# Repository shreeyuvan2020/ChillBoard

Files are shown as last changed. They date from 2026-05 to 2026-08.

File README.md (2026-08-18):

 # The Chillboard
 ## The perfect ergonomic keyboard for chilling
 ## Features
 - Uses Xiao NRF52840 for low power usage and BLE capabilities
 - Wireless design with a 2000 mAh battery and BLE
 - CPG1350 hotswap sockets for customizabilty
 - Low profile choc switches for portability
 - Neopixel backlighting for layer switching
 - OLED panel for battery percentage
 - Tray mounted for easy assembly
 - Rotary encoder for volume control
 - PIR sensor for energy conservation
 - Ortholinear layout with a thumb cluster to reduce strain
## Reasons I built this
 - Right now, I type on a laptop keyboard and am scared that I might get carpal tunnel.
 - The switches on my other keyboard are very loud, and are not the best for me. Hotswap sockets let me customize the feel.
 - The keyboard doesn't have backlighting.
## Schematic
 For the schematic, I used hierarchial sheets to organize everything. There are 2 hierarchial sheets for each side of the pcb, and a hierarchial sheet in each one of those for the large neopixel matrix. 

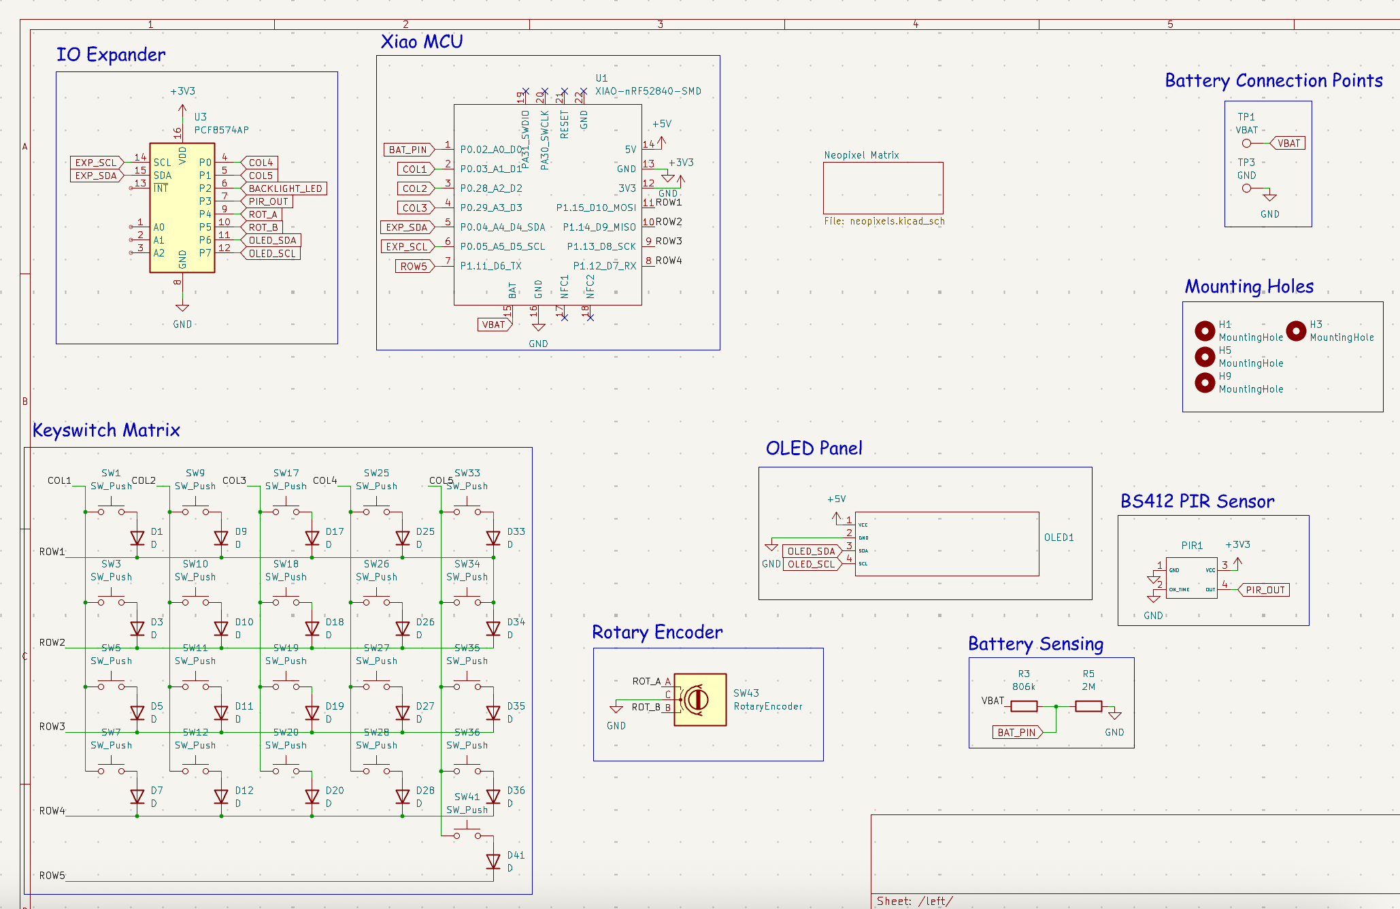
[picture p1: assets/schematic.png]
Schematic
 - 
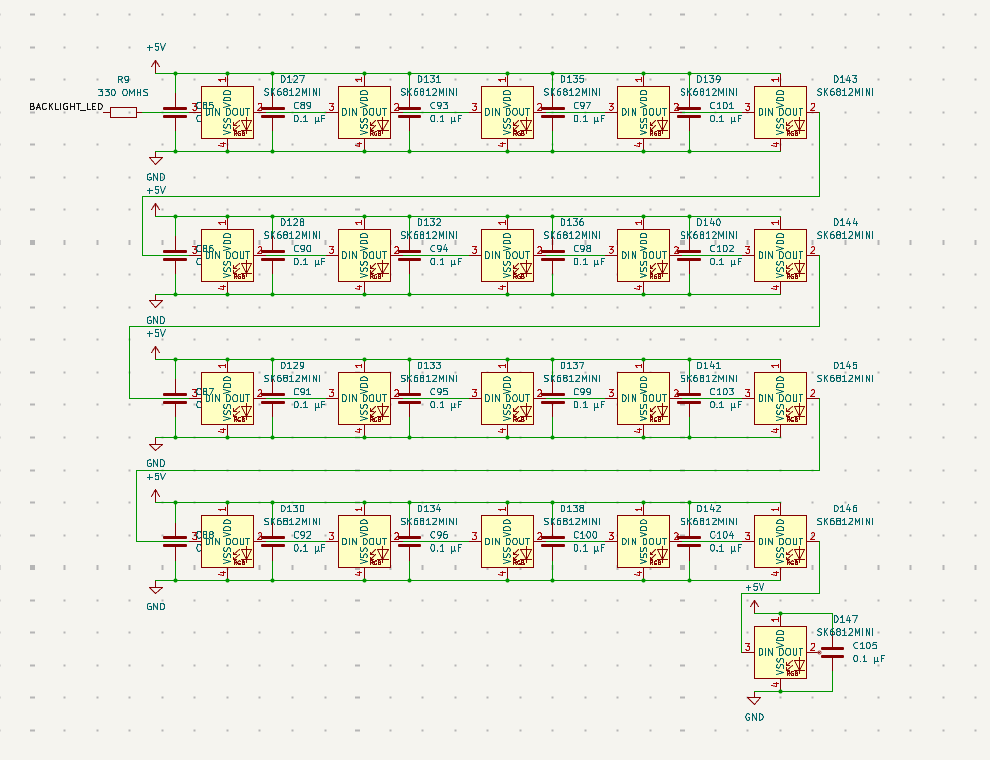
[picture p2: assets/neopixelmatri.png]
Neopixels
 - 
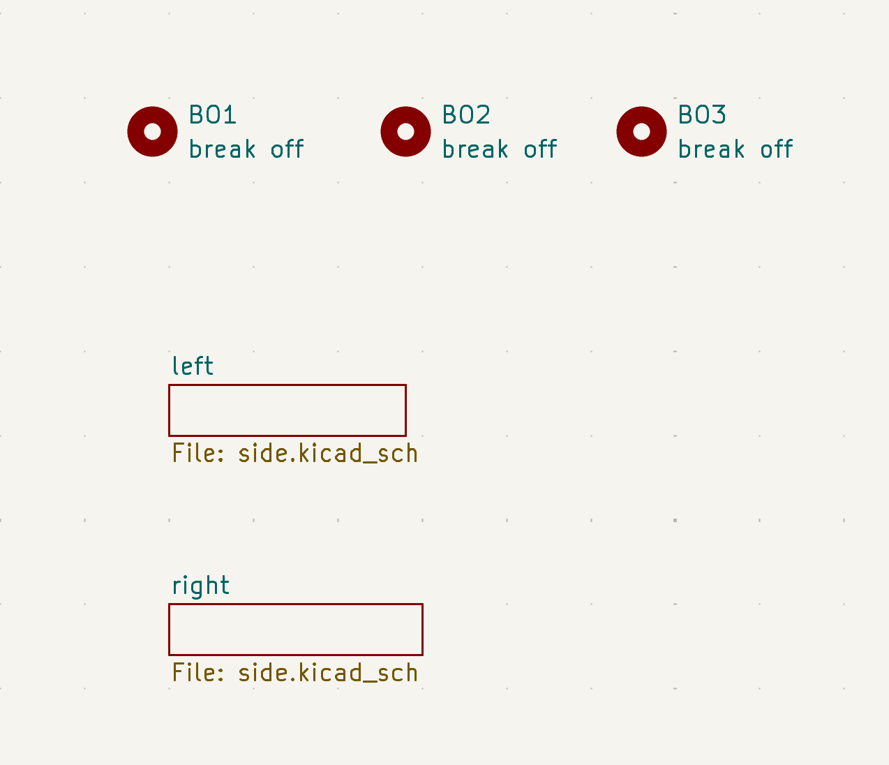
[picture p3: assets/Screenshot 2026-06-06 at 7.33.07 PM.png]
FullFull
 - 
## PCB
 I designed the PCB with mousebites to make the split keyboard easy to manufacture. I thought of making a reversible PCB at first, but it would be very difficult with an OLED. 
  ### Left side of the PCB 
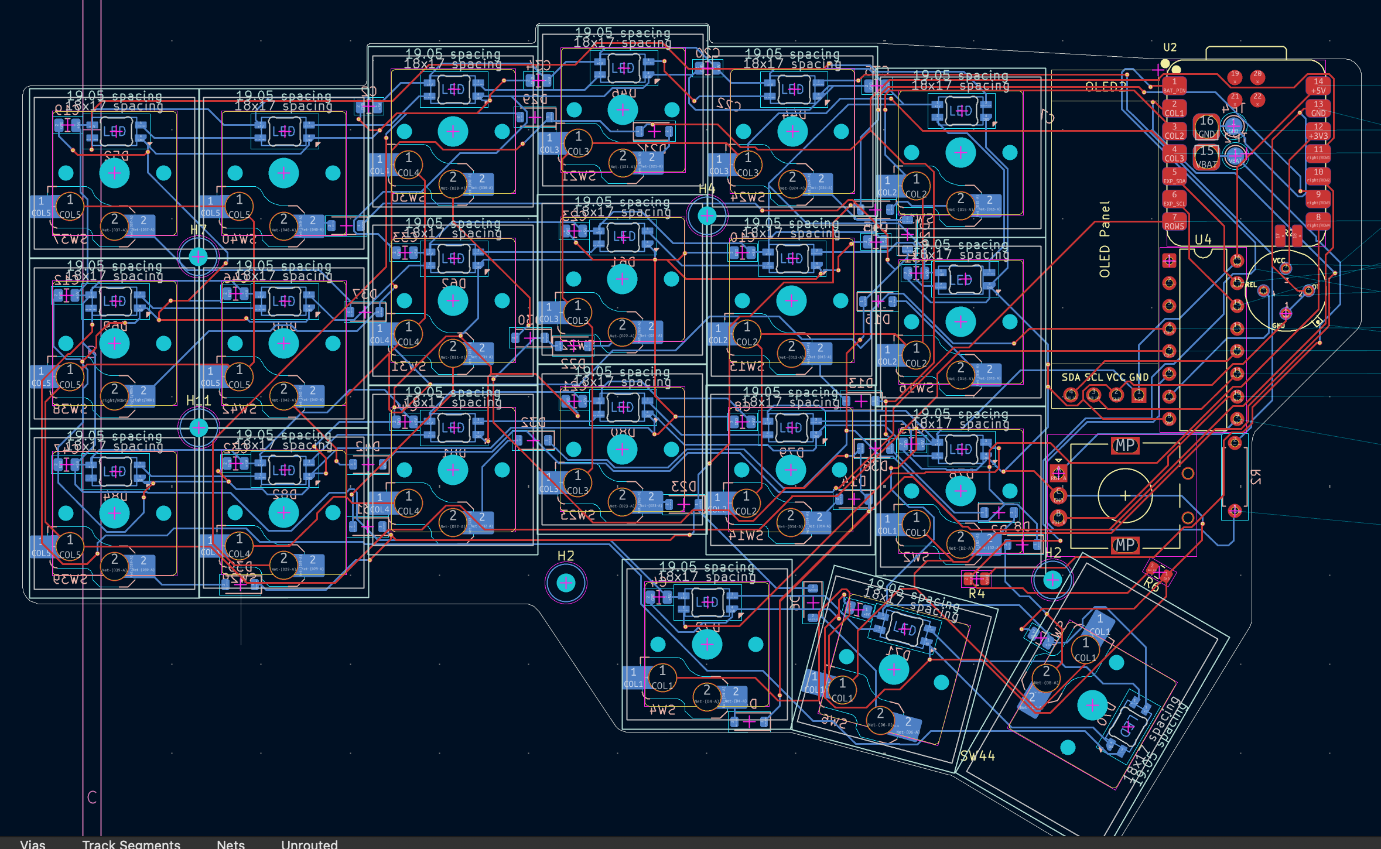
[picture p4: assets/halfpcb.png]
Left
  
  ### Full PCB
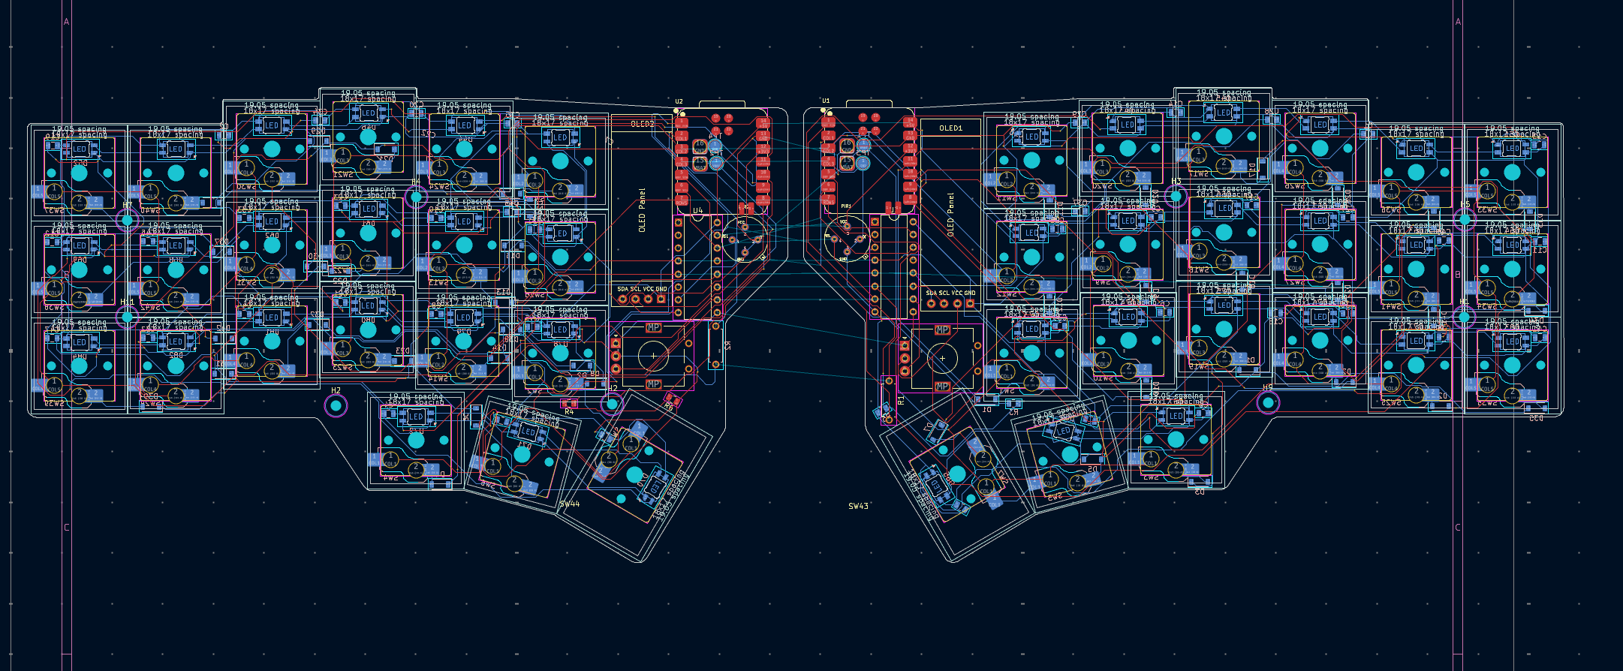
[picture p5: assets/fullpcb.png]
Full
  
  ### 3D View
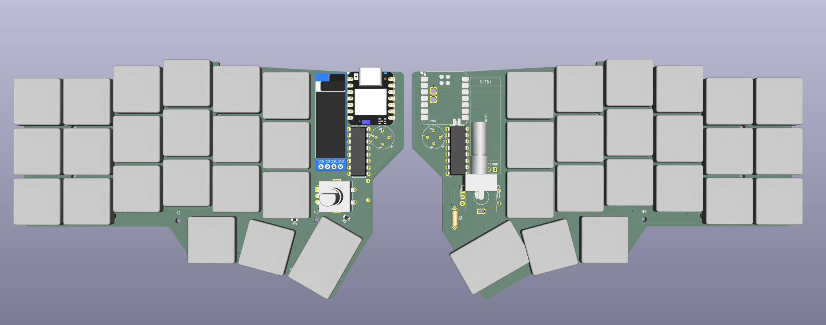
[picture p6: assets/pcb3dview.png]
3D
  
## CAD
 I designed the CAD with ease of assembly in mind. That is why I designed it with no tolerances, so that it could completely friction fit(I added screw holes for the worst case). I decided to print it with an extra fine setting on my Bambu Lab A1 Mini 3D printer, and it turned out great. 
 ### Bottom Case
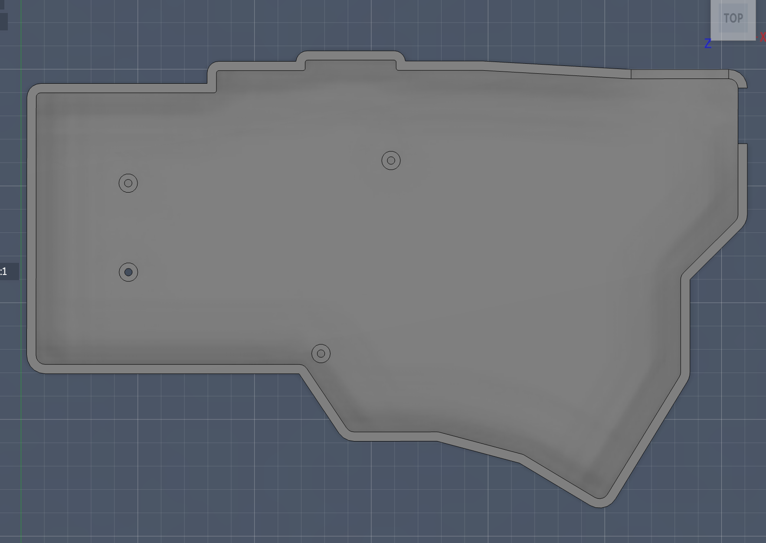
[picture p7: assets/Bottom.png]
Bottom
 
 ### Top Plate
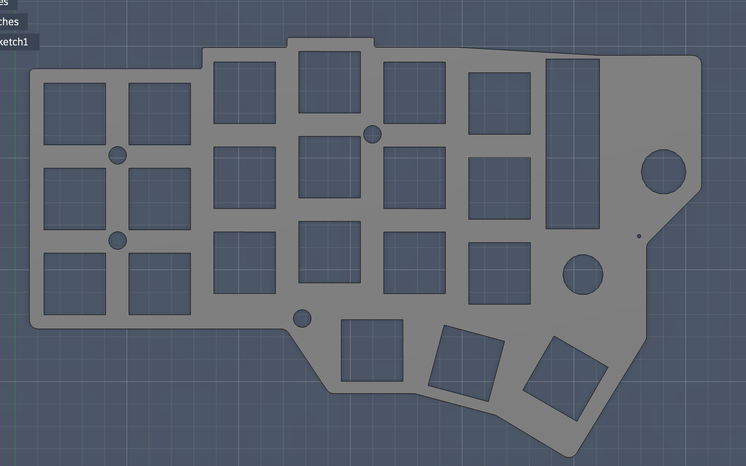
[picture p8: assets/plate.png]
Plate
 
 ### Full Assembly
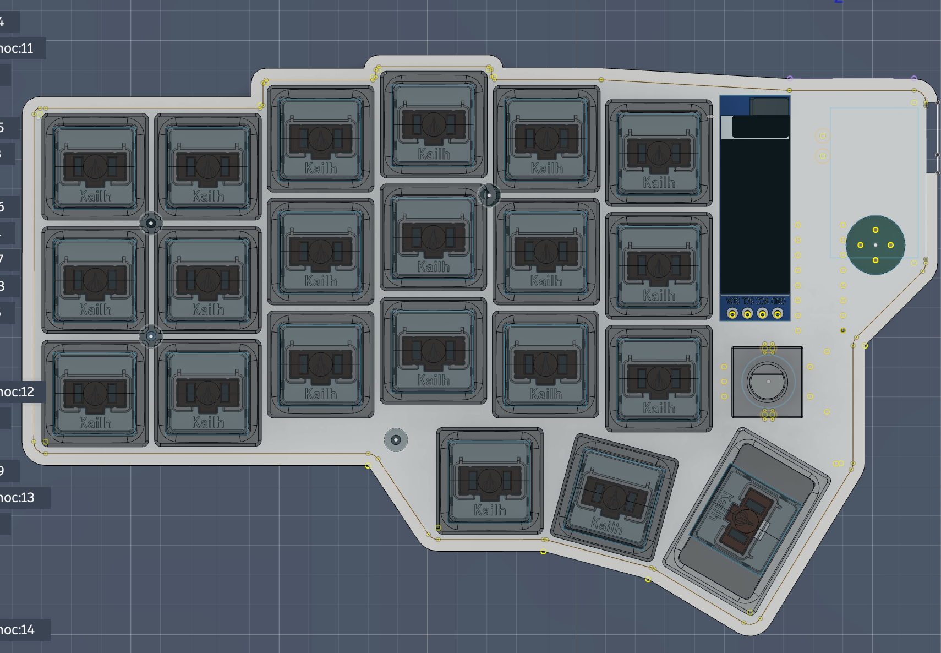
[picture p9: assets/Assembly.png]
Assembly
 
 ### Pictures of it Assembled
 Assembly
 Assembly
## My Zine
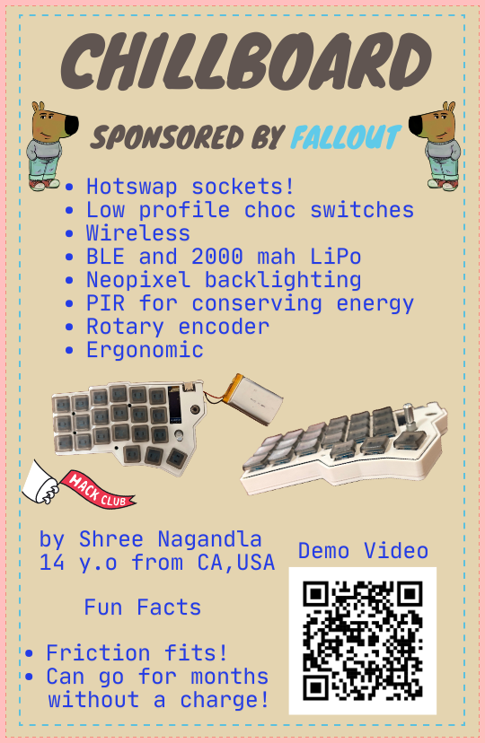
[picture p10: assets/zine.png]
zine

Zine is at zine.pdf too
## Assembly Instructions
 - First, obviously fabricate the PCB and solder everything.
 - Next is printing the plate and case.
 - Print with very fine settings as it friction fits, I printed with 0.08 mm High Quality @BBL on my Bambu Labs A1 Mini.
 - Be careful when removing the plate and bottom from the print bed as it could break
 - Obviously print two of each, two plates and two bottom cases
 - Then, go into the Firmware folder, open the submodule, and open Github Actions
 - Click the latest build and download the firmware artifact.
 - Then, plug in a USB cable into the Xiao and hit the reset button 2 times
 - A drive should show up, drop the first file that says settings-reset etc.
 - The drive should disappear, wait about 5 seconds and then do the same thing again
 - Then drop the file that starts with custom21
 - Now disconnect the cable, and it should show up as a BLE device
 - Connect to it then put the PCB into the bottom case
 - Then put the plate on top of it and place the keycaps on top of that to secure it.
 - You're good to go!
## Credits
 This project is inspired by the Corneucopia project by @DynamicWhiteHat.
 It used Autodesk Fusion for CAD, Kicad 10 for the PCB, and is sponsored by Hack Club Fallout! Thanks to Hack Club for sponsoring this!

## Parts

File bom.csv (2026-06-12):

Description | Price | Link
70 Low Profile Kailh Switches | 21.32 | https://www.aliexpress.us/item/3256811624147176.html
1N4148 SOD 123 Diodes | 0.51 | https://www.lcsc.com/product-detail/C33962554.html
0.1 uF 0805 Capacitors | 1.07 | https://www.lcsc.com/product-detail/C14663.html
45 SK6812MINI-E LED | 3.92 | https://www.lcsc.com/product-detail/C5149201.html
50 CPG1350 Sockets | 11.9 | https://www.amazon.com/Mechkeeb-Kailh-Low-Hot-swappable-Socket/dp/B0BS3JYJJQ?th=1
2 EC11 Rotary Encoders | 4 | https://www.lcsc.com/product-detail/C470754.html?
0.91 Inch SSD1306 OLED | 4.45 | https://www.lcsc.com/product-detail/C5248081.html
BS412 PIR Sensors | 2.05 | https://www.lcsc.com/product-detail/C410378.html
PCF8574AP | 1.59 | https://www.lcsc.com/product-detail/C398072.html?
2M Ohm Resistor | 0.22 | https://www.lcsc.com/product-detail/C2907316.html?
2 XIAO nrf52840 | 24.78 | https://www.seeedstudio.com/Seeed-XIAO-BLE-nRF52840-p-5201.html
PCB Order + Stencil | 24.63
Customs | Will Cover Myself
Total | 100.44

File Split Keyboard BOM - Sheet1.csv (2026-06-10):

Description | Price | Link | Column 4 | Column 5 | Column 6
Low Profile Kailh Switches | 29.61 | https://www.amazon.com/Mechanical-Keyboard-switches-Chocolate-Blue-70Pcs
1N4148 SOD 123 Diodes | 0.51 | https://www.lcsc.com/product-detail/C33962554.html
0.1 uF 0805 Capacitors | 1.07 | https://www.lcsc.com/product-detail/C14663.html
45 SK6812MINI-E LED | 3.92 | https://www.lcsc.com/product-detail/C5149201.html
50 CPG151101S11 Sockets | 7.9 | https://www.amazon.com/Hot-swap-CPG151101S11-Mechanical-Keyboard-Accessories/dp/B0BVH6M5FP?th=1
2 EC11 Rotary Encoders | 4 | https://www.lcsc.com/product-detail/C470754.html?
0.91 Inch SSD1306 OLED | 4.45 | https://www.lcsc.com/product-detail/C5248081.html
BS412 PIR Sensor | 2.05 | https://www.lcsc.com/product-detail/C410378.html
PCF8574AP | 1.59 | https://www.lcsc.com/product-detail/C398072.html?
2M Ohm Resistor | 0.22 | https://www.lcsc.com/product-detail/C2907316.html?
2 XIAO nrf52840 | 24.78 | https://www.seeedstudio.com/Seeed-XIAO-BLE-nRF52840-p-5201.html
PCB Order + Stencil | 24.63
DHL Customs | 43.98
Total | 148.71

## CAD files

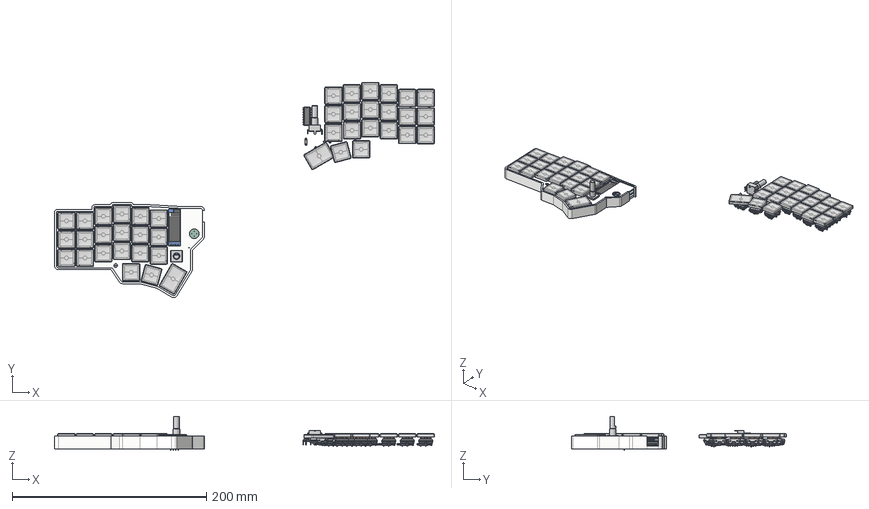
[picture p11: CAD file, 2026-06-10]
CAD/StepFiles/chillboardrender.step
391.2 x 221.6 x 35.4 mm
Chillboard_PCB
chillboardplate
OLED_0.91_128x32_1
Pin Header 4 x 1 TH 2.54mm Pitch
RESC-0603 x 13
2SD0601A
R_0805_2012Metric x 4
RotaryEncoder_Alps_EC11E_Vertical_H20mm x 2
DIP-16_W7.62mm x 2
chillboardtuffie6 1.7.1
R_Axial_DIN0207_L6.3mm_D2.5mm_P7.62mm_Horizontal x 2
LED_SK6812MINI-E x 42
C_0805_2012Metric x 42
D_SOD-123 x 42
pin x 84
socket x 42
SW_Kailh_Choc_V1 x 42
1x1 x 40
1x1.5 x 2
Chillboard_PCB_1

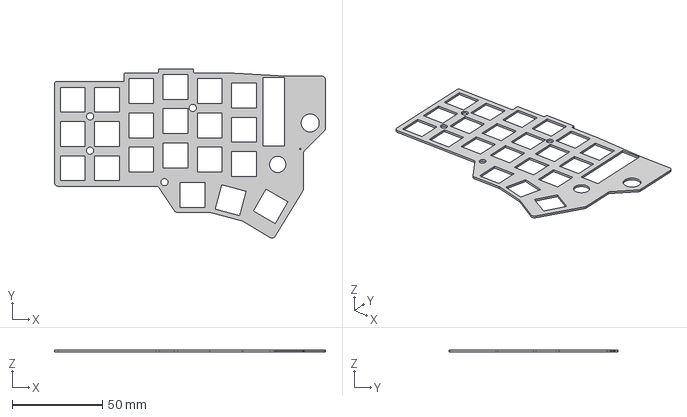
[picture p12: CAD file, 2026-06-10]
CAD/StepFiles/chillboardplate.step
150.3 x 93.9 x 1.20 mm

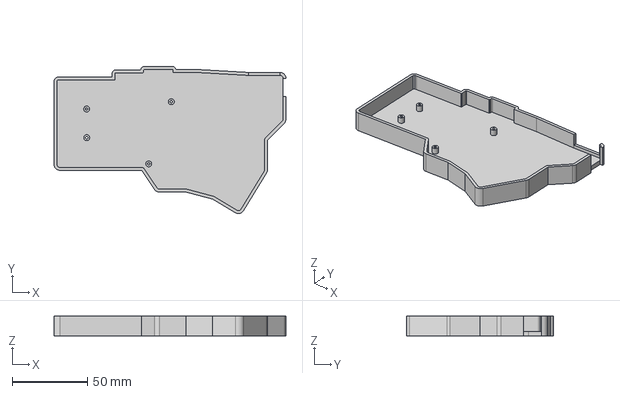
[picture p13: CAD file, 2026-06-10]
CAD/StepFiles/chillboardbot.step
154.3 x 97.9 x 13.0 mm

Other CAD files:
CAD/FusionFiles/chillboardassembly.f3z
CAD/FusionFiles/chillboardbottom.f3d
CAD/FusionFiles/chillboardplate.f3d

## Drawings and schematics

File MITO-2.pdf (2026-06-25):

# CHILLBOARD

## SPONSORED BY FALLOUT

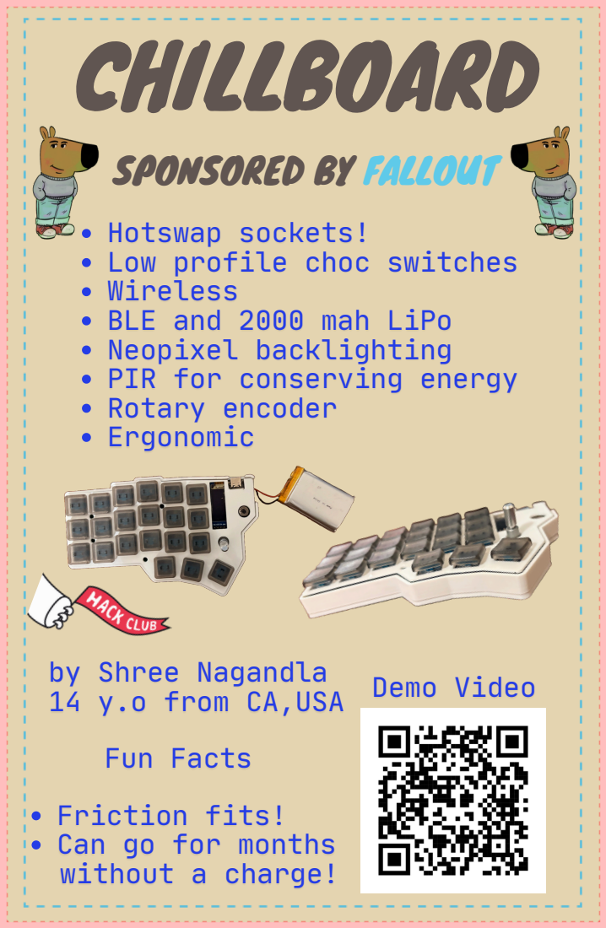
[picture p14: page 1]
Demo Video

Hotswap sockets!
Low profile choc switches
Wireless
BLE and 2000 mah LiPo
Neopixel backlighting
PIR for conserving energy
Rotary encoder
Ergonomic

by Shree Nagandla
14 y.o from CA,USA
Fun Facts
Friction fits!
Can go for months
without a charge!

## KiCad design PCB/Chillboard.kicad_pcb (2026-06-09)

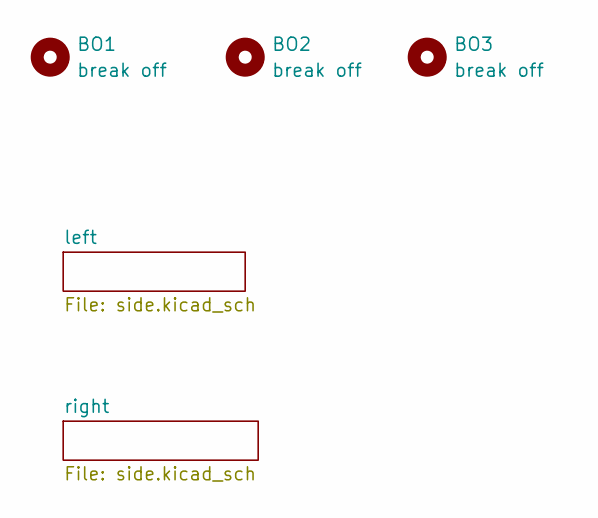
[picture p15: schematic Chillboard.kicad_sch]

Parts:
BO1, BO2, BO3: break off; mouse-bite-3mm-slot

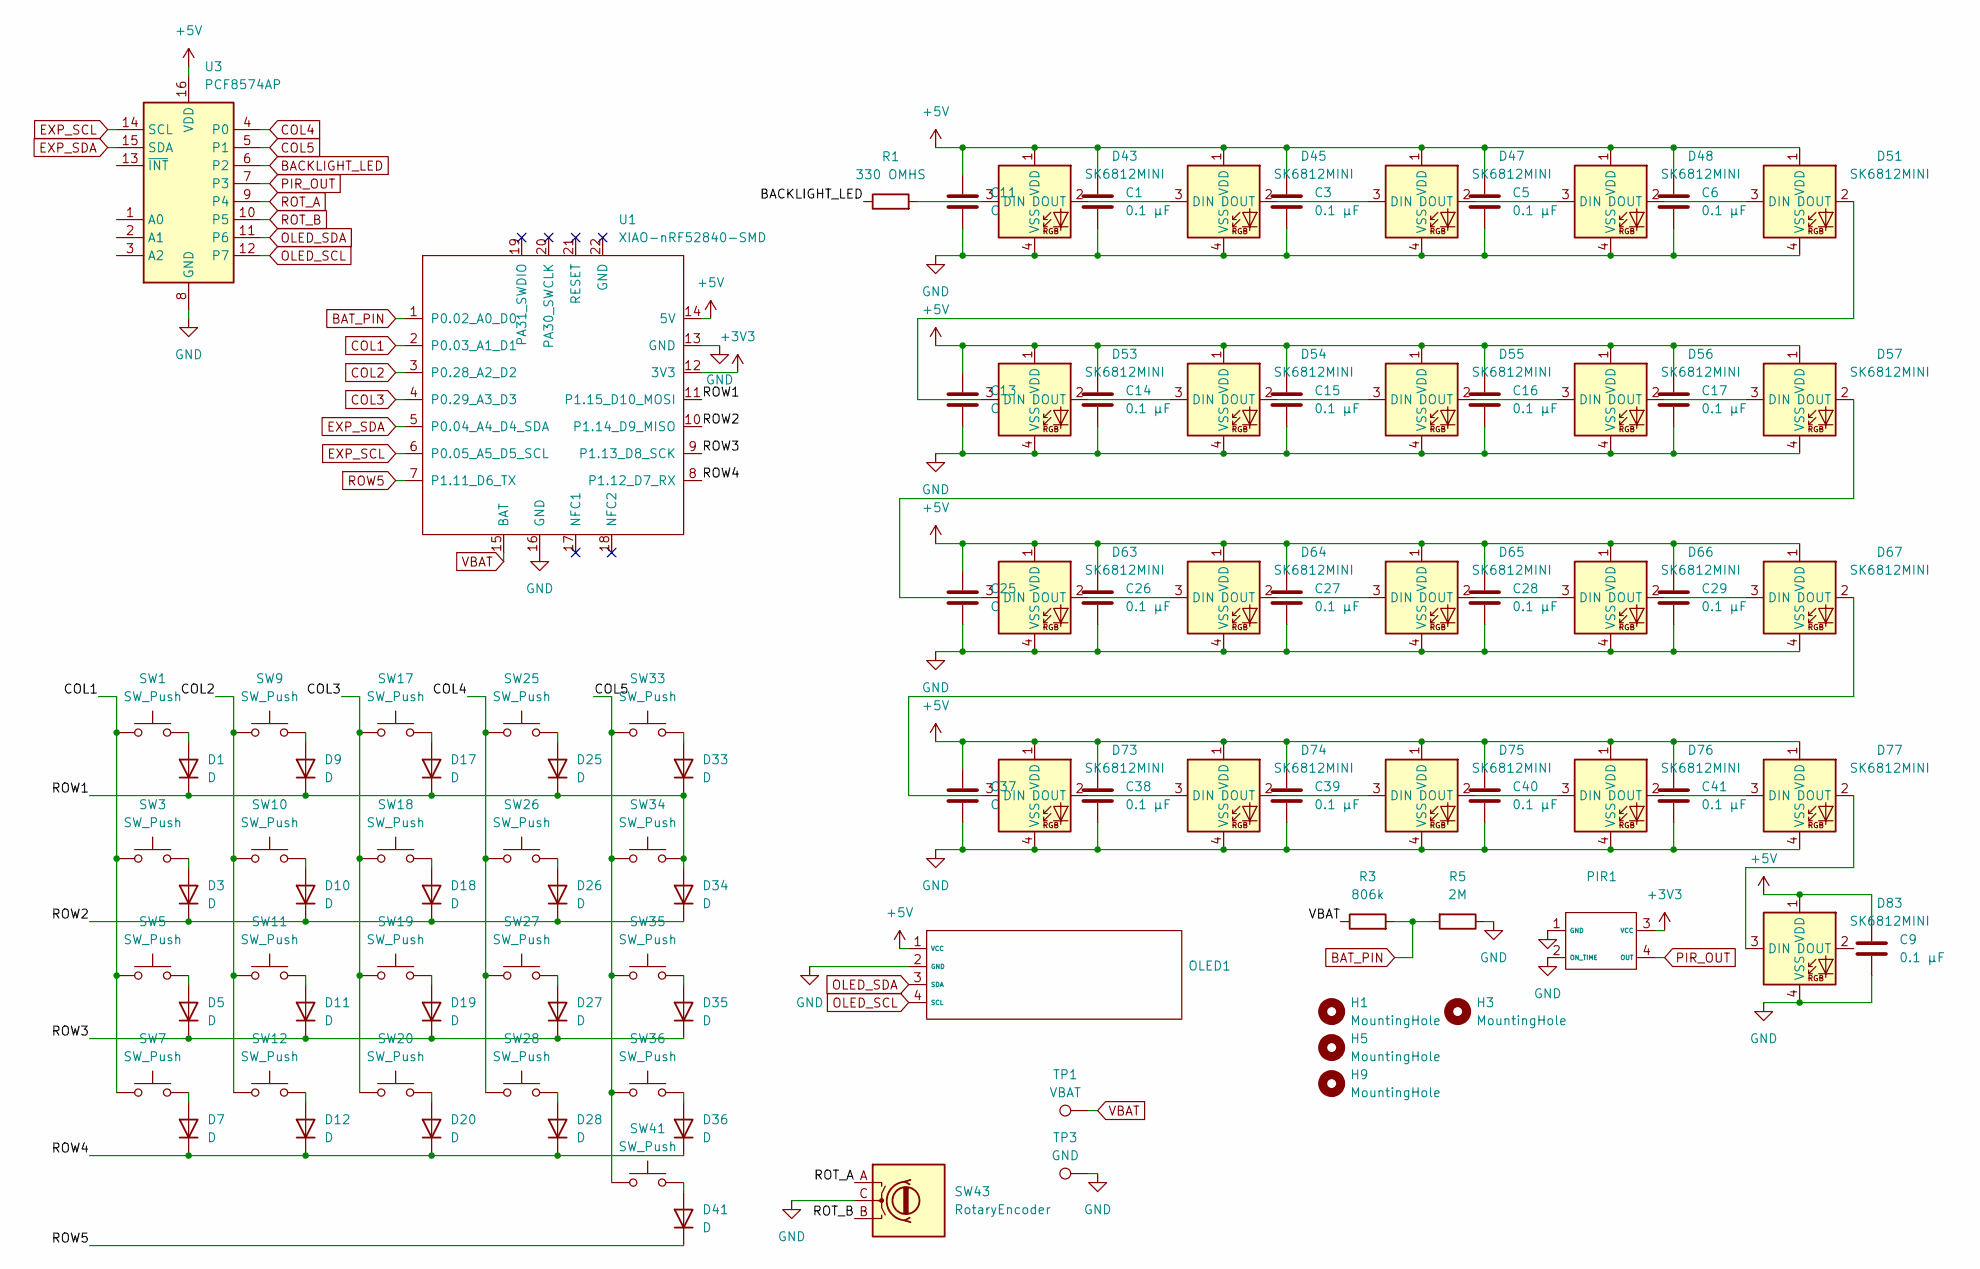
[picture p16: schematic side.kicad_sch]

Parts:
C1, C3, C5, C6, C9, C14, C15, C16, C17, C26, C27, C28, C29, C38, C39, C40, C41: 0.1 μF; C_0805_2012Metric
C11, C13, C25, C37: C; C_0805_2012Metric
D1, D3, D5, D7, D9, D10, D11, D12, D17, D18, D19, D20, D25, D26, D27, D28, D33, D34, D35, D36, D41: D; D_SOD-123
D43, D45, D47, D48, D51, D53, D54, D55, D56, D57, D63, D64, D65, D66, D67, D73, D74, D75, D76, D77, D83: SK6812MINI; LED_6028R
H1, H3, H5, H9: MountingHole; MountingHole_2.1mm
OLED1: SSD1306-0.91-OLED-4pin-128x32
PIR1: BS412
R1: 330 OMHS; R_Axial_DIN0207_L6.3mm_D2.5mm_P7.62mm_Horizontal
R3: 806k; R_0805_2012Metric
R5: 2M; R_0805_2012Metric
SW1, SW3, SW5, SW9, SW10, SW11, SW12, SW17, SW18, SW19, SW20, SW25, SW26, SW27, SW28, SW33, SW34, SW35, SW36, SW41: SW_Push; SW_choc_v1_HS_CPG135001S30_1u
SW7: SW_Push; SW_choc_v1_HS_CPG135001S30_1.5u
SW43: RotaryEncoder; RotaryEncoder_Alps_EC11E_Vertical_H20mm
TP1: VBAT; TestPoint_Pad_D2.0mm
TP3: GND; TestPoint_Pad_D2.0mm
U1: XIAO-nRF52840-SMD; modified-XIAO-nRF52840-SMD
U3: PCF8574AP; DIP-16_W7.62mm

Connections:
+3V3: PIR1.3 (VCC), U1.12 (3V3); also elsewhere on the board
+5V: C1.1, C3.1, C5.1, C6.1, C9.1, C11.1, C13.1, C14.1, C15.1, C16.1, C17.1, C25.1, C26.1, C27.1, C28.1, C29.1, C37.1, C38.1, C39.1, C40.1, C41.1, D43.1 (VDD), D45.1 (VDD), D47.1 (VDD), D48.1 (VDD), D51.1 (VDD), D53.1 (VDD), D54.1 (VDD), D55.1 (VDD), D56.1 (VDD), D57.1 (VDD), D63.1 (VDD), D64.1 (VDD), D65.1 (VDD), D66.1 (VDD), D67.1 (VDD), D73.1 (VDD), D74.1 (VDD), D75.1 (VDD), D76.1 (VDD), D77.1 (VDD), D83.1 (VDD), OLED1.1 (VCC), U1.14 (5V), U3.16 (VDD); also elsewhere on the board
/left/ROW1: D1.1 (K), D9.1 (K), D17.1 (K), D25.1 (K), D33.1 (K), D34.2 (A), SW34.2, U1.11 (P1.15_D10_MOSI)
/left/ROW2: D3.1 (K), D10.1 (K), D18.1 (K), D26.1 (K), D34.1 (K), U1.10 (P1.14_D9_MISO)
/left/ROW3: D5.1 (K), D11.1 (K), D19.1 (K), D27.1 (K), D35.1 (K), U1.9 (P1.13_D8_SCK)
/left/ROW4: D7.1 (K), D12.1 (K), D20.1 (K), D28.1 (K), D36.1 (K), U1.8 (P1.12_D7_RX)
BACKLIGHT_LED: R1.1, U3.6 (P2); also elsewhere on the board
BAT_PIN: R3.2, R5.2, U1.1 (P0.02_A0_D0); also elsewhere on the board
COL1: SW1.1, SW3.1, SW5.1, SW7.1, U1.2 (P0.03_A1_D1); also elsewhere on the board
COL2: SW9.1, SW10.1, SW11.1, SW12.1, U1.3 (P0.28_A2_D2); also elsewhere on the board
COL3: SW17.1, SW18.1, SW19.1, SW20.1, U1.4 (P0.29_A3_D3); also elsewhere on the board
COL4: SW25.1, SW26.1, SW27.1, SW28.1, U3.4 (P0); also elsewhere on the board
COL5: SW33.1, SW34.1, SW35.1, SW36.1, SW41.1, U3.5 (P1); also elsewhere on the board
EXP_SCL: U1.6 (P0.05_A5_D5_SCL), U3.14 (SCL); also elsewhere on the board
EXP_SDA: U1.5 (P0.04_A4_D4_SDA), U3.15 (SDA); also elsewhere on the board
GND: C1.2, C3.2, C5.2, C6.2, C9.2, C11.2, C13.2, C14.2, C15.2, C16.2, C17.2, C25.2, C26.2, C27.2, C28.2, C29.2, C37.2, C38.2, C39.2, C40.2, C41.2, D43.4 (VSS), D45.4 (VSS), D47.4 (VSS), D48.4 (VSS), D51.4 (VSS), D53.4 (VSS), D54.4 (VSS), D55.4 (VSS), D56.4 (VSS), D57.4 (VSS), D63.4 (VSS), D64.4 (VSS), D65.4 (VSS), D66.4 (VSS), D67.4 (VSS), D73.4 (VSS), D74.4 (VSS), D75.4 (VSS), D76.4 (VSS), D77.4 (VSS), D83.4 (VSS), OLED1.2 (GND), PIR1.1 (GND), PIR1.2 (ON_TIME), R5.1, SW43.C, TP3.1 (1_1), U1.13 (GND), U1.16 (GND), U3.8 (GND); also elsewhere on the board
unnamed: D1.2 (A), SW1.2
unnamed: D3.2 (A), SW3.2
unnamed: D5.2 (A), SW5.2
unnamed: D7.2 (A), SW7.2
unnamed: D9.2 (A), SW9.2
unnamed: D10.2 (A), SW10.2
unnamed: D11.2 (A), SW11.2
unnamed: D12.2 (A), SW12.2
unnamed: D17.2 (A), SW17.2
unnamed: D18.2 (A), SW18.2
unnamed: D19.2 (A), SW19.2
unnamed: D20.2 (A), SW20.2
unnamed: D25.2 (A), SW25.2
unnamed: D26.2 (A), SW26.2
unnamed: D27.2 (A), SW27.2
unnamed: D28.2 (A), SW28.2
unnamed: D33.2 (A), SW33.2
unnamed: D35.2 (A), SW35.2
unnamed: D36.2 (A), SW36.2
unnamed: D41.2 (A), SW41.2
unnamed: D43.3 (DIN), R1.2
unnamed: D43.2 (DOUT), D45.3 (DIN)
unnamed: D45.2 (DOUT), D47.3 (DIN)
unnamed: D47.2 (DOUT), D48.3 (DIN)
unnamed: D48.2 (DOUT), D51.3 (DIN)
unnamed: D51.2 (DOUT), D53.3 (DIN)
unnamed: D53.2 (DOUT), D54.3 (DIN)
unnamed: D54.2 (DOUT), D55.3 (DIN)
unnamed: D55.2 (DOUT), D56.3 (DIN)
unnamed: D56.2 (DOUT), D57.3 (DIN)
unnamed: D57.2 (DOUT), D63.3 (DIN)
unnamed: D63.2 (DOUT), D64.3 (DIN)
unnamed: D64.2 (DOUT), D65.3 (DIN)
unnamed: D65.2 (DOUT), D66.3 (DIN)
unnamed: D66.2 (DOUT), D67.3 (DIN)
unnamed: D67.2 (DOUT), D73.3 (DIN)
unnamed: D73.2 (DOUT), D74.3 (DIN)
unnamed: D74.2 (DOUT), D75.3 (DIN)
unnamed: D75.2 (DOUT), D76.3 (DIN)
unnamed: D76.2 (DOUT), D77.3 (DIN)
unnamed: D77.2 (DOUT), D83.3 (DIN)
OLED_SCL: OLED1.4 (SCL), U3.12 (P7); also elsewhere on the board
OLED_SDA: OLED1.3 (SDA), U3.11 (P6); also elsewhere on the board
PIR_OUT: PIR1.4 (OUT), U3.7 (P3); also elsewhere on the board
ROT_A: SW43.A, U3.9 (P4); also elsewhere on the board
ROT_B: SW43.B, U3.10 (P5); also elsewhere on the board
ROW5: D41.1 (K), U1.7 (P1.11_D6_TX); also elsewhere on the board
VBAT: R3.1, TP1.1 (1_1), U1.15 (BAT); also elsewhere on the board

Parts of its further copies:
C2, C4, C7, C8, C10, C20, C21, C22, C23, C32, C33, C34, C35, C44, C45, C46, C47: 0.1 μF; C_0805_2012Metric
C12, C19, C31, C43: C; C_0805_2012Metric
D2, D4, D6, D8, D13, D14, D15, D16, D21, D22, D23, D24, D29, D30, D31, D32, D37, D38, D39, D40, D42: D; D_SOD-123
D44, D46, D49, D50, D52, D58, D59, D60, D61, D62, D68, D69, D70, D71, D72, D78, D79, D80, D81, D82, D84: SK6812MINI; LED_6028R
H2, H4, H7, H11: MountingHole; MountingHole_2.1mm
R2: 330 OMHS; R_Axial_DIN0207_L6.3mm_D2.5mm_P7.62mm_Horizontal
R4: 806k; R_0805_2012Metric
R6: 2M; R_0805_2012Metric
SW2, SW4, SW6, SW13, SW14, SW15, SW16, SW21, SW22, SW23, SW24, SW29, SW30, SW31, SW32, SW37, SW38, SW39, SW40, SW42: SW_Push; SW_choc_v1_HS_CPG135001S30_1u
SW8: SW_Push; SW_choc_v1_HS_CPG135001S30_1.5u
SW44: RotaryEncoder; RotaryEncoder_Alps_EC11E_Vertical_H20mm
TP2: VBAT; TestPoint_Pad_D2.0mm
TP4: GND; TestPoint_Pad_D2.0mm
U2: XIAO-nRF52840-SMD; modified-XIAO-nRF52840-SMD
U4: PCF8574AP; DIP-16_W7.62mm

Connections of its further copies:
+3V3: U2.12 (3V3); also elsewhere on the board
+5V: C2.1, C4.1, C7.1, C8.1, C10.1, C12.1, C19.1, C20.1, C21.1, C22.1, C23.1, C31.1, C32.1, C33.1, C34.1, C35.1, C43.1, C44.1, C45.1, C46.1, C47.1, D44.1 (VDD), D46.1 (VDD), D49.1 (VDD), D50.1 (VDD), D52.1 (VDD), D58.1 (VDD), D59.1 (VDD), D60.1 (VDD), D61.1 (VDD), D62.1 (VDD), D68.1 (VDD), D69.1 (VDD), D70.1 (VDD), D71.1 (VDD), D72.1 (VDD), D78.1 (VDD), D79.1 (VDD), D80.1 (VDD), D81.1 (VDD), D82.1 (VDD), D84.1 (VDD), U2.14 (5V), U4.16 (VDD); also elsewhere on the board
/right/ROW1: D2.1 (K), D13.1 (K), D21.1 (K), D29.1 (K), D37.1 (K), D38.2 (A), SW38.2, U2.11 (P1.15_D10_MOSI)
/right/ROW2: D4.1 (K), D14.1 (K), D22.1 (K), D30.1 (K), D38.1 (K), U2.10 (P1.14_D9_MISO)
/right/ROW3: D6.1 (K), D15.1 (K), D23.1 (K), D31.1 (K), D39.1 (K), U2.9 (P1.13_D8_SCK)
/right/ROW4: D8.1 (K), D16.1 (K), D24.1 (K), D32.1 (K), D40.1 (K), U2.8 (P1.12_D7_RX)
BACKLIGHT_LED: R2.1, U4.6 (P2); also elsewhere on the board
BAT_PIN: R4.2, R6.2, U2.1 (P0.02_A0_D0); also elsewhere on the board
COL1: SW2.1, SW4.1, SW6.1, SW8.1, U2.2 (P0.03_A1_D1); also elsewhere on the board
COL2: SW13.1, SW14.1, SW15.1, SW16.1, U2.3 (P0.28_A2_D2); also elsewhere on the board
COL3: SW21.1, SW22.1, SW23.1, SW24.1, U2.4 (P0.29_A3_D3); also elsewhere on the board
COL4: SW29.1, SW30.1, SW31.1, SW32.1, U4.4 (P0); also elsewhere on the board
COL5: SW37.1, SW38.1, SW39.1, SW40.1, SW42.1, U4.5 (P1); also elsewhere on the board
EXP_SCL: U2.6 (P0.05_A5_D5_SCL), U4.14 (SCL); also elsewhere on the board
EXP_SDA: U2.5 (P0.04_A4_D4_SDA), U4.15 (SDA); also elsewhere on the board
GND: C2.2, C4.2, C7.2, C8.2, C10.2, C12.2, C19.2, C20.2, C21.2, C22.2, C23.2, C31.2, C32.2, C33.2, C34.2, C35.2, C43.2, C44.2, C45.2, C46.2, C47.2, D44.4 (VSS), D46.4 (VSS), D49.4 (VSS), D50.4 (VSS), D52.4 (VSS), D58.4 (VSS), D59.4 (VSS), D60.4 (VSS), D61.4 (VSS), D62.4 (VSS), D68.4 (VSS), D69.4 (VSS), D70.4 (VSS), D71.4 (VSS), D72.4 (VSS), D78.4 (VSS), D79.4 (VSS), D80.4 (VSS), D81.4 (VSS), D82.4 (VSS), D84.4 (VSS), R6.1, SW44.C, TP4.1 (1_1), U2.13 (GND), U2.16 (GND), U4.8 (GND); also elsewhere on the board
unnamed: D2.2 (A), SW2.2
unnamed: D4.2 (A), SW4.2
unnamed: D6.2 (A), SW6.2
unnamed: D8.2 (A), SW8.2
unnamed: D13.2 (A), SW13.2
unnamed: D14.2 (A), SW14.2
unnamed: D15.2 (A), SW15.2
unnamed: D16.2 (A), SW16.2
unnamed: D21.2 (A), SW21.2
unnamed: D22.2 (A), SW22.2
unnamed: D23.2 (A), SW23.2
unnamed: D24.2 (A), SW24.2
unnamed: D29.2 (A), SW29.2
unnamed: D30.2 (A), SW30.2
unnamed: D31.2 (A), SW31.2
unnamed: D32.2 (A), SW32.2
unnamed: D37.2 (A), SW37.2
unnamed: D39.2 (A), SW39.2
unnamed: D40.2 (A), SW40.2
unnamed: D42.2 (A), SW42.2
unnamed: D44.3 (DIN), R2.2
unnamed: D44.2 (DOUT), D46.3 (DIN)
unnamed: D46.2 (DOUT), D49.3 (DIN)
unnamed: D49.2 (DOUT), D50.3 (DIN)
unnamed: D50.2 (DOUT), D52.3 (DIN)
unnamed: D52.2 (DOUT), D58.3 (DIN)
unnamed: D58.2 (DOUT), D59.3 (DIN)
unnamed: D59.2 (DOUT), D60.3 (DIN)
unnamed: D60.2 (DOUT), D61.3 (DIN)
unnamed: D61.2 (DOUT), D62.3 (DIN)
unnamed: D62.2 (DOUT), D68.3 (DIN)
unnamed: D68.2 (DOUT), D69.3 (DIN)
unnamed: D69.2 (DOUT), D70.3 (DIN)
unnamed: D70.2 (DOUT), D71.3 (DIN)
unnamed: D71.2 (DOUT), D72.3 (DIN)
unnamed: D72.2 (DOUT), D78.3 (DIN)
unnamed: D78.2 (DOUT), D79.3 (DIN)
unnamed: D79.2 (DOUT), D80.3 (DIN)
unnamed: D80.2 (DOUT), D81.3 (DIN)
unnamed: D81.2 (DOUT), D82.3 (DIN)
unnamed: D82.2 (DOUT), D84.3 (DIN)
OLED_SCL: U4.12 (P7); also elsewhere on the board
OLED_SDA: U4.11 (P6); also elsewhere on the board
PIR_OUT: U4.7 (P3); also elsewhere on the board
ROT_A: SW44.A, U4.9 (P4); also elsewhere on the board
ROT_B: SW44.B, U4.10 (P5); also elsewhere on the board
ROW5: D42.1 (K), U2.7 (P1.11_D6_TX); also elsewhere on the board
VBAT: R4.1, TP2.1 (1_1), U2.15 (BAT); also elsewhere on the board

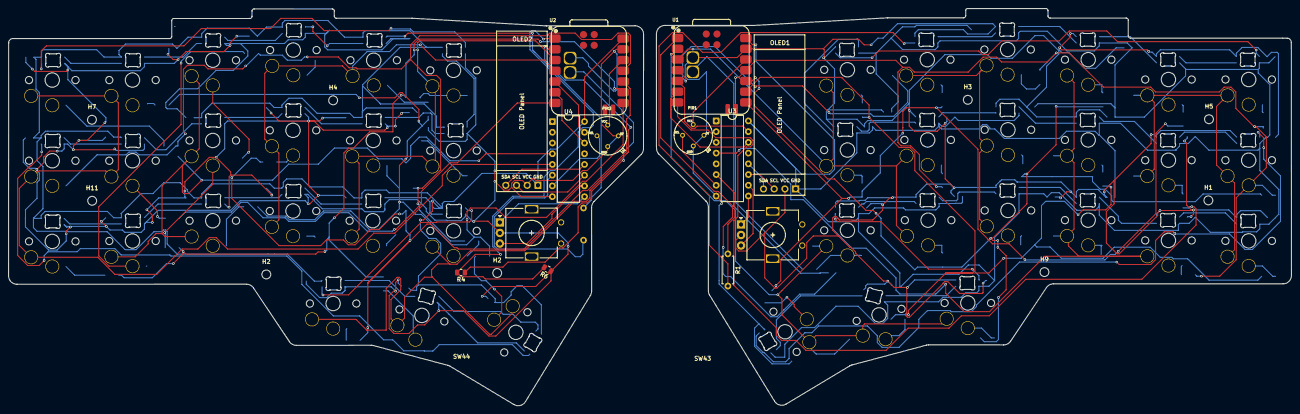
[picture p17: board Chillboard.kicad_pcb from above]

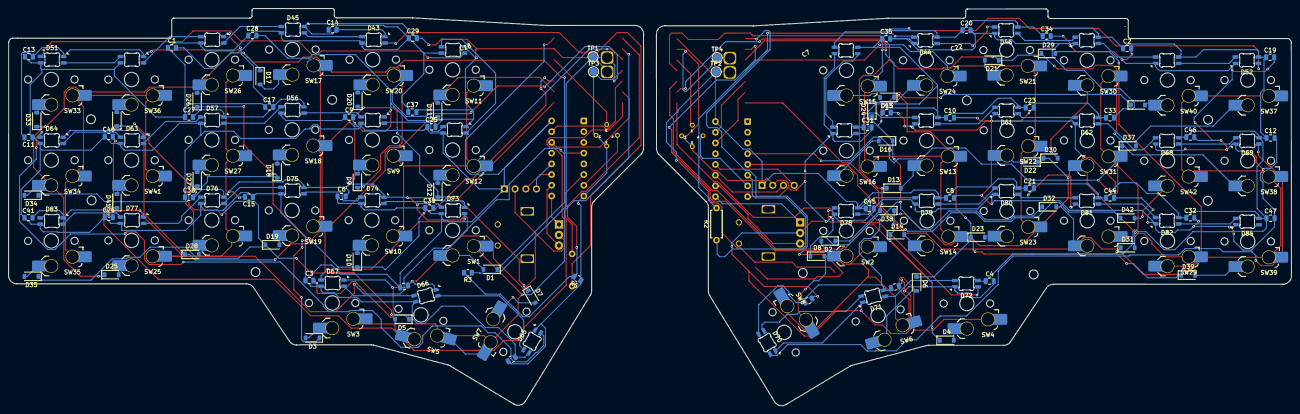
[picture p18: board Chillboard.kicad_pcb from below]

Board: 2 copper layers, 303.7 x 94.0 mm, 197 parts (175 on the bottom side), 109 nets.

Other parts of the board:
H2#2: MountingHole; MountingHole_2.1mm
OLED2: SSD1306-0.91-OLED-4pin-128x32
PIR2: BS412

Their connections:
+3V3: PIR2.3 (VCC); also elsewhere on the board
+5V: OLED2.1 (VCC); also elsewhere on the board
GND: OLED2.2 (GND), PIR2.1 (GND), PIR2.2 (ON_TIME); also elsewhere on the board
OLED_SCL: OLED2.4 (SCL); also elsewhere on the board
OLED_SDA: OLED2.3 (SDA); also elsewhere on the board
PIR_OUT: PIR2.4 (OUT); also elsewhere on the board

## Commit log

2026-05-01 deleted stuff
    [aortaalarm.kicad_pcb, aortaalarm.kicad_sch]
2026-06-07 readme stuff
    [.step, chillboardtuffie6.step, therealchillboardwithcomponents.step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]
2026-06-09 Reorganize repository: clean .gitignore and move libraries/3D-models/exports to organized folders
    - Added comprehensive .gitignore for KiCad generated files, caches, macOS artifacts, and build outputs
    - Moved 3D model files (*.step, *.wrl) to 3D-Models/
    - Moved symbol libraries to libraries/symbols/
    - Moved footprint libraries to libraries/footprints/custom/ and libraries/footprints/panelization/
    - Moved exports (DXF, SVG, Gerbers.zip) to generated-exports/
    - Removed incorrectly tracked files: lock files, cache files, backup files, generated renders
    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
    [.step, Chillboard-Edge_Cuts.dxf, Chillboard.csv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]
2026-06-09 Reorganize into main project categories: PCB, CAD, Manufacturing, Firmware, Documentation
    - PCB/: KiCad project files (schematics, board layout) + symbol/footprint libraries
    - CAD/: 3D models (.step, .wrl) + design exports (DXF, SVG)
    - Manufacturing/: Gerber files + project backups
    - Firmware/: ZMK keyboard firmware configuration
    - Documentation/: Project images and assets
    This hierarchical structure improves project navigation and clarity.
    [Chillboard-Edge_Cuts.dxf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]
2026-06-09 Track assets folder in version control
    - Updated .gitignore to allow assets/ directory despite *.png pattern
    - Added all project images to version control
2026-06-10 add bom
    [Split Keyboard BOM - Sheet1.csv]
2026-06-10 add fusion files
    [chillboardassembly.f3z, chillboardbottom.f3d, chillboardplate.f3d]
2026-06-10 add step
    [.step, chillboardbot.step, chillboardplate.step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]
2026-06-10 organize into cad folder
    [chillboardassembly.f3z, chillboardbottom.f3d, chillboardplate.f3d]
2026-06-10 organize cad folder
    [chillboardassembly.f3z, chillboardbot.step, chillboardbottom.f3d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]
2026-06-10 make it to bom.csv instead of weird name
    [bom.csv]
2026-06-10 add assembly instructions
2026-06-11 make bom.csv optimized
    [bom.csv]
2026-06-11 make it coolio
    [bom.csv]
2026-06-11 add sockets
    [bom.csv]
2026-06-12 change key switches
    [bom.csv]
2026-06-12 change to remove customs,. new total
    [bom.csv]
2026-06-12 make it cool
    [bom.csv]
2026-06-12 change for ez description ig
    [bom.csv]
2026-06-12 make assembly clear
2026-06-25 add built
    Added pictures of the assembled project to the README.
2026-06-25 add pics
    Replaced old assembly images with new HEIC format images.
2026-08-18 make some of the images unborked(heic to png)
    Replaced old assembly images with new top and side view images.
